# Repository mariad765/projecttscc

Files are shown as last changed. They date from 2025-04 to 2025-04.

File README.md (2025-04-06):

# projecttscc
date: 2025

# Proiect: OpenBook
Acest proiect utilizează Autodesk Fusion 360 pentru realizarea designului carcasei și a plăcii PCB pentru OpenBook, având la bază microcontrollerul ESP32-C6. Include senzori, module de alimentare și componente conectate prin diverse interfețe.

# Diagrama Bloc

### General:
```
+------------------------+     +------------------------+     +------------------------+
| USB-C + ESD Protection | --> | LDO Voltage Regulator  | --> | Li-Po Charging Ctrl.   |
+------------------------+     +------------------------+     +------------------------+
                                                            |
                                                            v
                                                      +----------------+
                                                      |   Battery      |
                                                      | (3.7V Li-Po)   |
                                                      +----------------+
                                                            |
                                                            v
+------------------+     +------------------+         +-------------------+
| RTC DS3231SN     |<--->|   ESP32-C6       |<------->| E-Paper Display   |
+------------------+     +------------------+         | (Header + Driver) |
                           ^    ^   ^   ^              +-------------------+
                           |    |   |   |
       +------------------+    |   |   +--------------------+
       |                       |   |                        |
       v                       v   v                        v
+--------------+       +--------------+           +----------------------+
| SD Card Slot |       | BME688 Sensor|           | External Flash 64MB  |
+--------------+       +--------------+           +----------------------+
                           ^   |
                           |   v
               +-----------------------------+
               | Voltage Supervisor + Reset  |
               | Boot / IO Button Module     |
               +-----------------------------+

                           ^
                           |
                    +-------------+
                    | EPD Power   |
                    +-------------+

                           ^
                           |
              +-----------------------+
              | SPI ESD Protection    |
              +-----------------------+

                           ^
                           |
            +--------------------------+
            | Qwic / Stemma QT Header |
            +--------------------------+

                           ^
                           |
                     +-----------+
                     | Test Pads |
                     +-----------+

```

### Organizarea componentelor mici:
```

                        +------------------------+
                        | USB-C + ESD Protection |
                        | R1, F1, D1             |
                        +-----------+------------+
                                    |
                                    v
                      +-----------------------------+
                      | LDO Voltage Regulator       |
                      | U4 (XC6220)                 |
                      | D2 (Schottky)               |
                      | C1, C2 (Capacitors)         |
                      +-----------+-----------------+
                                  |
                                  v
          +----------------------------------------------+
          | Li-Po Charging Controller (MCP73831)         |
          | RPROG, C1_BAT, C2_BAT                        |
          +--------------------+-------------------------+
                               |
                               v
                          +---------+
                          | Battery |
                          +---------+

          +------------------------------------------+
          |                ESP32-C6                  |
          | U2, conectat cu GPIO la toate modulele   |
          +--+--------+----------+----------+--------+
             |        |          |          |
             |        |          |          |
             |        |          |          |
             v        v          v          v
+------------------+ +------------------+ +-------------------+ +-------------------+
| RTC DS3231SN     | | BME688 Sensor    | | E-Paper Display   | | External NOR Flash|
| U3, C1, C2       | | Ux, Cx (Filter)  | | Header + Drive    | | U1, Cx (Decouple) |
| + CRYSTAL        | | R (Pull-ups)     | | Q3 (MOSFET),      | |                   |
+------------------+ +------------------+ | L1 (Inductor),    | +-------------------+
                                          | D3, D4 (Diodes)   |
                                          | C3, C4, C5, C6    |
                                          +-------------------+

                      +------------------------------------+
                      | SD Card Module (SPI)              |
                      | + Pull-up Resistors               |
                      +------------------------------------+
                      +--------------------------------------------+
                      | Voltage Supervisor + Boot + Reset Buttons  |
                      | Ux (BD52), R1, R2, C1, C2                   |
                      +--------------------------------------------+
                      +------------------+ +--------------------+
                      | EPD Power        | | SPI ESD Protection |
                      | Zener Diode      | | TVS Diodes         |
                      +------------------+ +--------------------+
                      +---------------------------+
                      | Qwiic / Stemma QT Header  |
                      | 4-Pin Connector           |
                      +---------------------------+

                      +---------------------------+
                      | Test Pads (TP1 - TP17)    |
                      +---------------------------+

```

#### Legenda componente:
R = Rezistențe (pull-up, pull-down, programare)

C = Condensatori (filtrare, decuplare, bypass)

D = Diode (Schottky, Zener, TVS)

Q = Tranzistori (MOSFET, BJT)

L = Bobine (inductoare pentru EPD)

U = Integrate (ESP32-C6, MCP73831, etc.)

TP = Test Pads

CRYSTAL = Oscilator 32.768kHz pentru RTC

<prev>

| **Device** | **Datasheet** | **Purchase URL** | **Notes** |
|---|---|---|---|
| ADAFRUIT_LEDCHIP-LED0603 | [Datasheet](https://dammedia.osram.info/media/resource/hires/osram-dam-5178061/LH%20R974_EN.pdf) | [Purchase](https://eu.mouser.com/ProductDetail/ams-OSRAM/LH-R974?qs=rUek3o0zKEvmwAoLLbCfCQ%3D%3D) | |
| ESP32_WROVER_EAGLE-LTSPICE_RR0402 | [Datasheet](https://eu.mouser.com/datasheet/2/447/PYu_RT_1_to_0_01_RoHS_L_15-3461507.pdf) | [Purchase](https://eu.mouser.com/ProductDetail/YAGEO/RT0402BRE072KL?qs=gY0y7AQI9SOEMRqvTCljCA%3D%3D) | |
| ESP32_WROVER_EAGLE-LTSPICE_RR0402 | [Datasheet](https://eu.mouser.com/datasheet/2/447/PYu_SR_20105_RoHS_L_12-3461462.pdf) | [Purchase](https://eu.mouser.com/ProductDetail/YAGEO/SR0402FR-0710KL?qs=TyBUSTk9pD%2F02BJ2PplVgA%3D%3D) | |
| EAGLE-LTSPICE_CC0402 | [Datasheet](https://eu.mouser.com/datasheet/2/447/KEM_C1003_C0G_SMD-3316496.pdf) | [Purchase](https://eu.mouser.com/ProductDetail/KEMET/C0402C100J4GACTU?qs=mjekseImwbbdX0mMb15eGA%3D%3D) | |
| SJ | [Datasheet](https://www.snapeda.com/parts/5112/Keystone%20Electronics/datasheet/) | [Purchase](https://eu.mouser.com/ProductDetail/Keystone-Electronics/5112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) | |
| ESP32_WROVER_EAGLE-LTSPICE_RR0402 | [Datasheet](https://eu.mouser.com/datasheet/2/447/PYu_RC_Group_51_RoHS_L_12-3368608.pdf) | [Purchase](https://eu.mouser.com/ProductDetail/YAGEO/RC0402FR-07226RL?qs=ZELcmBmapfyYDZKSOq20kw%3D%3D) | |
| EAGLE-LTSPICE_CC0402 | [Datasheet](https://eu.mouser.com/datasheet/2/447/KEM_C1018_X7R_SnPb_SMD-3316276.pdf) | [Purchase](https://eu.mouser.com/ProductDetail/KEMET/C0402C104K4RAL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) | |
| ESP32_WROVER_EAGLE-LTSPICE_CC0402 | [Datasheet](https://eu.mouser.com/datasheet/2/447/KEM_C1002_X7R_SMD-3316098.pdf) | [Purchase](https://eu.mouser.com/ProductDetail/KEMET/C0402C104K4RAC?qs=sykUljcfnH1GXndxGT8AHQ%3D%3D) | |
| RCL_CPOL-EUCT3528 | [Datasheet](https://www.snapeda.com/parts/OF-SMD3528WC/Optoflash/datasheet/) | [Purchase](https://www.tme.eu/en/details/of-smd3528wc/smd-white-leds/optoflash/) | |
| ESP32_WROVER_EAGLE-LTSPICE_CC0402 | [Datasheet](https://eu.mouser.com/datasheet/2/447/KEM_C1018_X7R_SnPb_SMD-3316276.pdf) | [Purchase](https://eu.mouser.com/ProductDetail/KEMET/C0402C104K4RAL?qs=pIZUS6sqCWCaMuP2QVR%2Fog%3D%3D) | |
| 112A-TAAR-R03_ATTEND | [Datasheet](https://www.snapeda.com/parts/112A-TAAR-R03/Attend/datasheet/) | [Purchase](https://www.tme.eu/ro/details/mcc-sdmicro/conectori-pentru-cartele/attend/112a-taar-r03/) | |
| EAGLE-LTSPICE_CC0402 | [Datasheet](https://eu.mouser.com/datasheet/2/447/KEM_C1006_X5R_SMD-3316465.pdf) | [Purchase](https://eu.mouser.com/ProductDetail/KEMET/C0402C475M9PAC7411?qs=cpo3%2FpBou2jRzZxyxJnMGg%3D%3D) | |
| ESP32_WROVER_SPARKFUN-DISCRETESEMI_MOSFET_PCH-DMG2305UX-7 | [Datasheet](https://www.diodes.com/assets/Datasheets/DMG2305UX.pdf) | [Purchase](https://eu.mouser.com/ProductDetail/Diodes-Incorporated/DMG2305UX-7?qs=L1DZKBg7t5F%2FNBHrjfxC%252Bg%3D%3D) | |
| 744043680IND_4828-WE-TPC_WRE | [Datasheet](https://www.we-online.com/components/products/datasheet/744043680.pdf) | [Purchase](https://eu.mouser.com/ProductDetail/Wurth-Elektronik/744043680?qs=PGXP4M47uW6VkZq%252BkzjrHA%3D%3D) | |
| BD5229G-TR | [Datasheet](https://fscdn.rohm.com/en/products/databook/datasheet/ic/power/voltage_detector/bd52xxg-e.pdf) | [Purchase](https://eu.mouser.com/ProductDetail/ROHM-Semiconductor/BD5229G-TR?qs=4kLU8WoGk0vvnhrrYwdszw%3D%3D) | |
| ESP32_WROVER_BME680_BME680 | [Datasheet](https://eu.mouser.com/datasheet/2/783/bst_bme688_fl000-2307034.pdf) | [Purchase](https://eu.mouser.com/ProductDetail/Bosch-Sensortec/BME688?qs=IS%252B4QmGtzzqQoVDscqwx3A%3D%3D) | |
| BUTTON_CUSYOMV1 | [Datasheet](https://www.ckswitches.com/media/1482/kms.pdf) | [Purchase](https://eu.mouser.com/ProductDetail/CK/KMS231G?qs=cygERTaPE9Aulmq4rq4WXQ%3D%3D) | [see note 1] |
| CPH3225A | [Datasheet](https://eu.mouser.com/datasheet/2/360/Seiko_Instruments_MicroBattery_E_20230330_2024Jan_-3561061.pdf) | [Purchase](https://eu.mouser.com/ProductDetail/Seiko-Semiconductors/CPH3225A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) | |
| DS3231SN# | [Datasheet](https://eu.mouser.com/datasheet/2/609/DS3231-3421123.pdf) | [Purchase](https://www.snapeda.com/api/url_track_click_mouser/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) | |
| ESP32-C6-WROOM-1-N8 | [Datasheet](https://eu.mouser.com/datasheet/2/891/Espressif_ESP32_C6_WROOM_1__Datasheet_V0_1_PRELIMI-3239987.pdf) | [Purchase](https://eu.mouser.com/ProductDetail/Espressif-Systems/ESP32-C6-WROOM-1-N8?qs=8Wlm6%252BaMh8ST02Gmwp74cw%3D%3D) | |
| ESP32C6_VARISTORCN1812 | [Datasheet](https://www.snapeda.com/parts/PFMF.050.2/Schurter/datasheet/) | [Purchase](https://www.digikey.com/en/products/detail/schurter-inc/PFMF-050-2/1731348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) | |
| ESP32_WROVER_AVX---SD0805S020S1R0_AVX_SD0805S020S1R0_0_0AVX_SD0805S020S1R0_0_0 | [Datasheet](http://datasheets.avx.com/schottky.pdf) | [Purchase](https://www.kyocera-avx.com/products/diodes/lead-less-chip-schottky-barrier-diodes/) | |
| ESP32_WROVER_SPARKFUN-IC-POWER_MCP73831 | [Datasheet](https://eu.mouser.com/datasheet/2/268/MCP73831_Family_Data_Sheet_DS20001984H-3441711.pdf) | [Purchase](https://eu.mouser.com/ProductDetail/Microchip-Technology/MCP73831T-2ACI-OT?qs=yUQqVecv4qvbBQBGbHx0Mw%3D%3D) | |
| FH34SRJ-24S-0.5SH_99_ | [Datasheet](https://www.snapeda.com/parts/FH34SRJ-24S-0.5SH(99)/Hirose%20Electric/datasheet/) | [Purchase](https://www.digikey.com/en/products/detail/hirose-electric-co-ltd/FH34SRJ-24S-0-5SH-99/5132529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) | |
| MAX17048G+T10 | [Datasheet](https://eu.mouser.com/datasheet/2/609/MAX17048_MAX17049-3469099.pdf) | [Purchase](https://www.snapeda.com/api/url_track_click_mouser/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) | |
| MBR0530 | [Datasheet](https://www.onsemi.com/products/discrete-power-modules/schottky-diodes-schottky-rectifiers/mbr0530t3g) | [Purchase](https://www.snapeda.com/api/url_track_click_mouser/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) | |
| PGB1010603MR | [Datasheet](https://www.littelfuse.com/assetdocs/pulseguard-esd-suppressors-pgb1-datasheet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) | [Purchase](https://www.snapeda.com/api/url_track_click_mouser/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) | 
| QWIIC_CONNECTORJS-1MM | [Qwiic Connector Datasheet](https://eu.mouser.com/datasheet/2/813/Qwiic_Connector_Datasheet-1223982.pdf) | [SparkFun Product](https://eu.mouser.com/ProductDetail/SparkFun/PRT-14417?qs=wd5RIQLrsJhgdz%2FpmZ%2F3GQ%3D%3D) | |
| SAMACSYS_PARTS_USB4110-GF-A | [USB4110 Product Drawing](https://eu.mouser.com/datasheet/2/837/GCT_USB4110_Product_Drawing___20k_cycles-3455479.pdf) | [GCT Product](https://eu.mouser.com/ProductDetail/GCT/USB4110-GF-A?qs=KUoIvG%2F9IlYiZvIXQjyJeA%3D%3D) | |
| SI1308EDL-T1-GE3 | [SI1308EDL Datasheet](https://www.vishay.com/docs/63399/si1308edl.pdf) | [Vishay Product](https://eu.mouser.com/ProductDetail/Vishay-Semiconductors/SI1308EDL-T1-GE3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) | |
| TPTP20R | [TPTP20R Datasheet](https://eu.mouser.com/datasheet/2/215/000-5004-741320.pdf)  | [Keystone Product](https://eu.mouser.com/ProductDetail/Keystone-Electronics/5000?qs=q0tsjPZWdm%252B9SiiTAbEwUw%3D%3D) | [see note 2] |
| USBLC6-2SC6Y | [USBLC6-2SC6Y Datasheet](https://eu.mouser.com/datasheet/2/389/usblc6_2sc6y-1852505.pdf) | [STMicroelectronics Product](https://eu.mouser.com/ProductDetail/STMicroelectronics/USBLC6-2SC6Y?qs=gNDSiZmRJS%2FOgDexvXkdow%3D%3D) | |
| W25Q512JVEIQ | [W25Q512JVEIQ Datasheet](https://eu.mouser.com/datasheet/2/949/Winbond_W25Q512JV_Datasheet-3240039.pdf) | [Winbond Product](https://eu.mouser.com/ProductDetail/Winbond/W25Q512JVEIQ?qs=l7cgNqFNU1jw6svr3at6tA%3D%3D) | |
| XC6220A331MR-G | [XC6220A331MR-G Datasheet](https://eu.mouser.com/datasheet/2/760/xc6220-3371556.pdf) | [Torex Semiconductor Product](https://eu.mouser.com/ProductDetail/Torex-Semiconductor/XC6220A331MR-G?qs=AsjdqWjXhJ8ZSWznL1J0gg%3D%3D) | |

</prev>

[note 1] - 
<prev>
✅ Side-Actuated Tactile Switches (Compatible with KMR2 footprint)
1. C&K KMS231G LFS
🔹 Size: 4.6 mm × 2.8 mm
🔹 Height: 1.9 mm
🔹 Actuation Force: 2.6 N
🔹 Type: Side push (side-actuated)
🔹 Mounting: SMT
🔹 Footprint Compatibility: ✅ (Matches KMR2 pad spacing)
</prev>
[note 2] - 
<prev>
TP20R is often associated with a round, 2.0 mm diameter test pad.
Here’s a commonly used and widely available match:

✅ Keystone Electronics 5000 Series
Model: Keystone 5000
Type: SMT Test Point
Material: Phosphor bronze
Plating: Tin over Nickel
Pad Diameter: Fits 2.0 mm pad
Mounting: Surface Mount
Aplication: General purpose test point for probes

✅ Harwin S1751-46R
Type: SMT Test Point
For Pad: ~2.0 mm diameter
Profile: Low
Finish: Tin
Common in: Test pads designed for probe contact

✅ Alternative: Mill-Max 2501-2-00-80-00-00-07-0
Type: Test Point/Contact Pad
Style: Coined terminal
Footprint Compatibility: Suitable with TP20R
Mount: SMT
Useful for: Precise contact with spring-loaded probes

</prev>

#  Funcționalitate hardware detaliată

Proiectul se bazează pe microcontrollerul ESP32-C6 ce coordonează următoarele module:

Alimentare:
USB-C -> protecție ESD + siguranță resetabilă + diodă Schottky
Regulator LDO 3.3V (XC6220)
MCP73831 încarcă un acumulator Li-Po

Afișaj E-Paper 2.9":
Alimentare dedicată EPD Power + MOSFET pentru control curent
Header 24 pini conectat prin SPI

Modul de ceas RTC DS3231SN:
Comunicare I²C
Precizie ridicată, cristale integrate

Senzor BME688:
Comunicare I²C
Măsoară presiune, temperatură, umiditate și compuși volatili

Memorie externă NOR Flash 64MB:
Interfață SPI

Slot SD Card:
SPI + pini selectabili pentru CS

Supraveghetor tensiune + Reset & Boot IO:
Butoane fizice pentru dezvoltare/debug

Protecție ESD (TVS):
Pe toate liniile SPI și I²C critice

Header Qwiic / Stemma QT:
Expansiune rapidă prin I²C

Paduri de test TP1-TP17:
Verificare și depanare ușoară

# Pini ESP32-C6 folosiți

```
| Pin   | Funcție      | Modul conectat                    |
|-------|--------------|-----------------------------------|
| IO2   | SPI CLK      | E-Paper, Flash, SD Card           |
| IO3   | SPI MISO     | Flash, SD Card                    |
| IO4   | SPI MOSI     | E-Paper, Flash, SD Card           |
| IO5   | SPI CS (selectabil) | Flash                          |
| IO6   | SPI CS       | SD Card                           |
| IO7   | SPI CS       | E-Paper                           |
| IO8   | I²C SDA      | RTC, BME688, Qwiic                |
| IO9   | I²C SCL      | RTC, BME688, Qwiic                |
| EN    | Enable       | Buton de reset                    |
| IO0   | Boot         | Buton boot                        |

```

# Alte resurse relevante

-> Design log: toate PCB-urile au fost create în Fusion 360 Electronics, folosind standarde de rutare pentru 3.3V și SPI/I²C.

-> Testare și depanare: TP1-TP17 permit sondare pentru verificare semnal

# Licență

Distribuit sub licența GNU GPL v3. Pentru detalii, consultă fișierul LICENSE din acest repository.

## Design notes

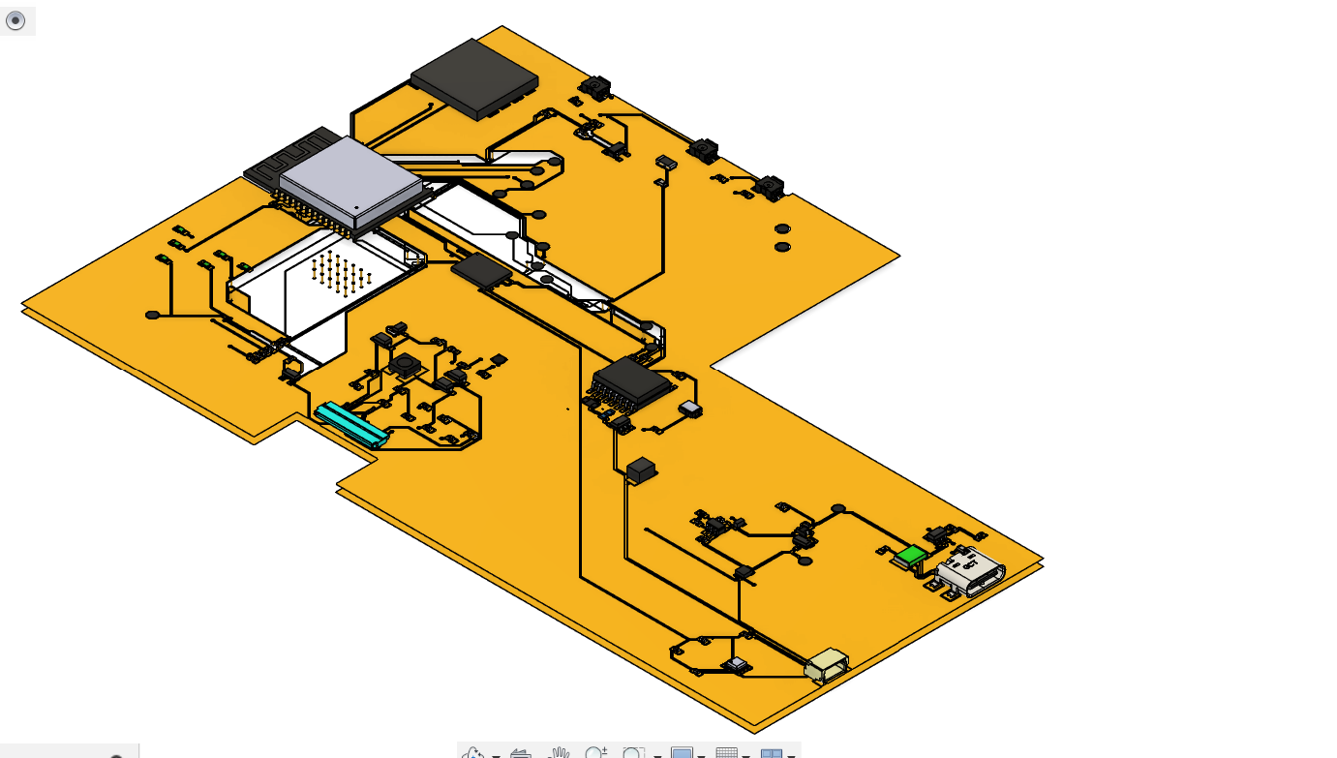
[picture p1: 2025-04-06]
Images/3d_placa.png

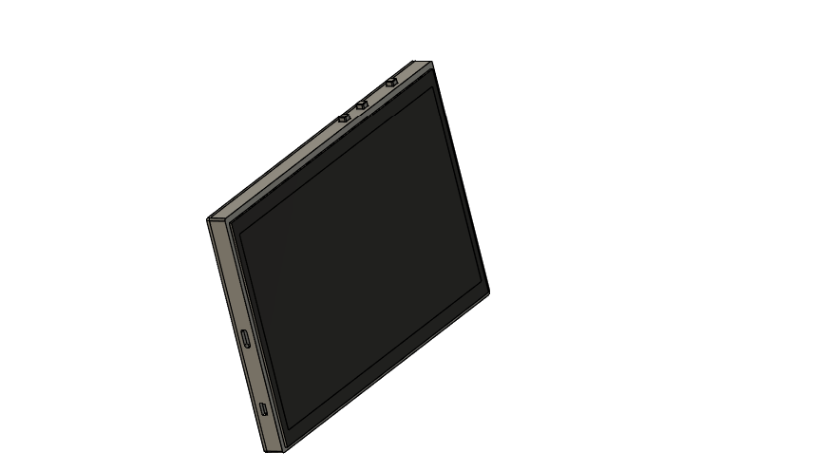
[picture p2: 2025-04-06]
Images/3d_dispozitiv.png

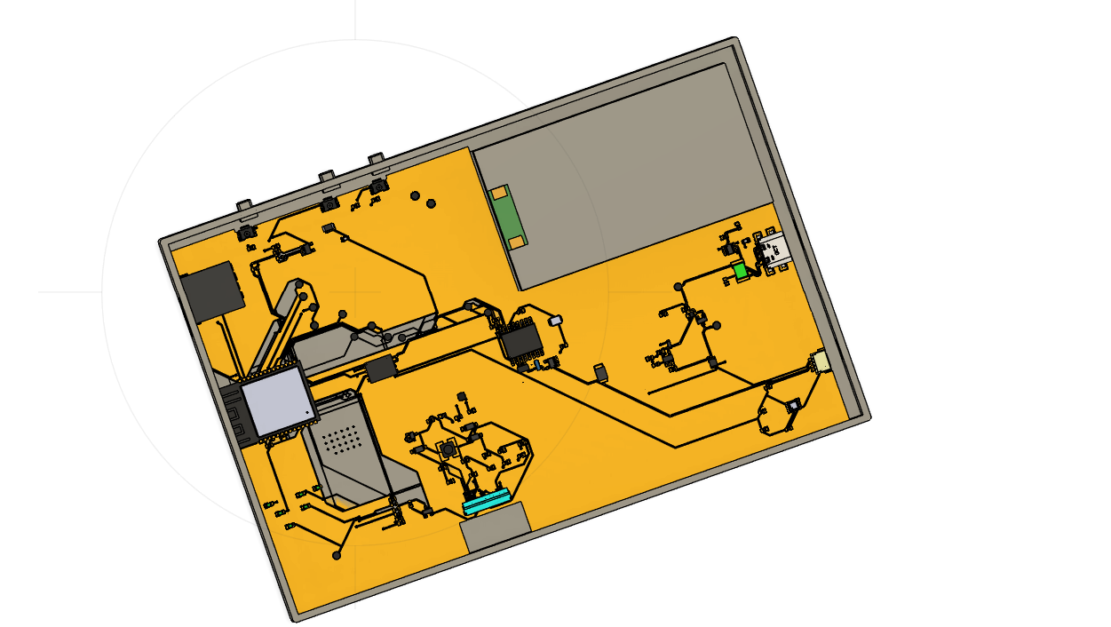
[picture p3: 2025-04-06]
Images/3d_dispozitiv_no lid.png

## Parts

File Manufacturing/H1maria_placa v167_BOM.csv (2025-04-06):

Device | DATASHEET | PURCHASE-URL
ADAFRUIT_LEDCHIP-LED0603 | https://dammedia.osram.info/media/resource/hires/osram-dam-5178061/LH%20R974_EN.pdf | https://eu.mouser.com/ProductDetail/ams-OSRAM/LH-R974?qs=rUek3o0zKEvmwAoLLbCfCQ%3D%3D
ESP32_WROVER_EAGLE-LTSPICE_RR0402
SJ
EAGLE-LTSPICE_CC0402
ESP32_WROVER_EAGLE-LTSPICE_RR0402
ESP32_WROVER_EAGLE-LTSPICE_RR0402
EAGLE-LTSPICE_CC0402
ESP32_WROVER_EAGLE-LTSPICE_CC0402
RCL_CPOL-EUCT3528
ESP32_WROVER_EAGLE-LTSPICE_RR0402
ESP32_WROVER_EAGLE-LTSPICE_CC0402
112A-TAAR-R03_ATTEND
ESP32_WROVER_EAGLE-LTSPICE_RR0402
EAGLE-LTSPICE_CC0402
EAGLE-LTSPICE_CC0402
ESP32_WROVER_EAGLE-LTSPICE_RR0402
ESP32_WROVER_EAGLE-LTSPICE_RR0402
ESP32_WROVER_SPARKFUN-DISCRETESEMI_MOSFET_PCH-DMG2305UX-7
ESP32_WROVER_EAGLE-LTSPICE_RR0402
EAGLE-LTSPICE_CC0402
ESP32_WROVER_EAGLE-LTSPICE_CC0402
ESP32_WROVER_EAGLE-LTSPICE_RR0402
744043680IND_4828-WE-TPC_WRE
BD5229G-TR
ESP32_WROVER_BME680_BME680
BUTTON_CUSYOMV1
CPH3225A |  | https://www.snapeda.com/api/url_track_click_mouser/?unipart_id=562593&manufacturer=Seiko Instruments&part_name=CPH3225A&search_term=None
DS3231SN# |  | https://www.snapeda.com/api/url_track_click_mouser/?unipart_id=99048&manufacturer=Analog Devices&part_name=DS3231SN#&search_term=None
ESP32-C6-WROOM-1-N8
ESP32C6_VARISTORCN1812
ESP32_WROVER_AVX---SD0805S020S1R0_AVX_SD0805S020S1R0_0_0AVX_SD0805S020S1R0_0_0 | http://datasheets.avx.com/schottky.pdf
ESP32_WROVER_SPARKFUN-IC-POWER_MCP73831
FH34SRJ-24S-0.5SH_99_
MAX17048G+T10 |  | https://www.snapeda.com/api/url_track_click_mouser/?unipart_id=329239&manufacturer=Analog Devices&part_name=MAX17048G+T10&search_term=None
MBR0530 |  | https://www.snapeda.com/api/url_track_click_mouser/?unipart_id=179458&manufacturer=ON Semiconductor&part_name=MBR0530&search_term=None
PGB1010603MR |  | https://www.snapeda.com/api/url_track_click_mouser/?unipart_id=5659453&manufacturer=Littelfuse Inc.&part_name=PGB1010603MR&search_term=None
QWIIC_CONNECTORJS-1MM
SAMACSYS_PARTS_USB4110-GF-A
ESP32_WROVER_AVX---SD0805S020S1R0_AVX_SD0805S020S1R0_0_0AVX_SD0805S020S1R0_0_0 | http://datasheets.avx.com/schottky.pdf
SI1308EDL-T1-GE3
TPTP20R
USBLC6-2SC6Y
W25Q512JVEIQ
XC6220A331MR-G

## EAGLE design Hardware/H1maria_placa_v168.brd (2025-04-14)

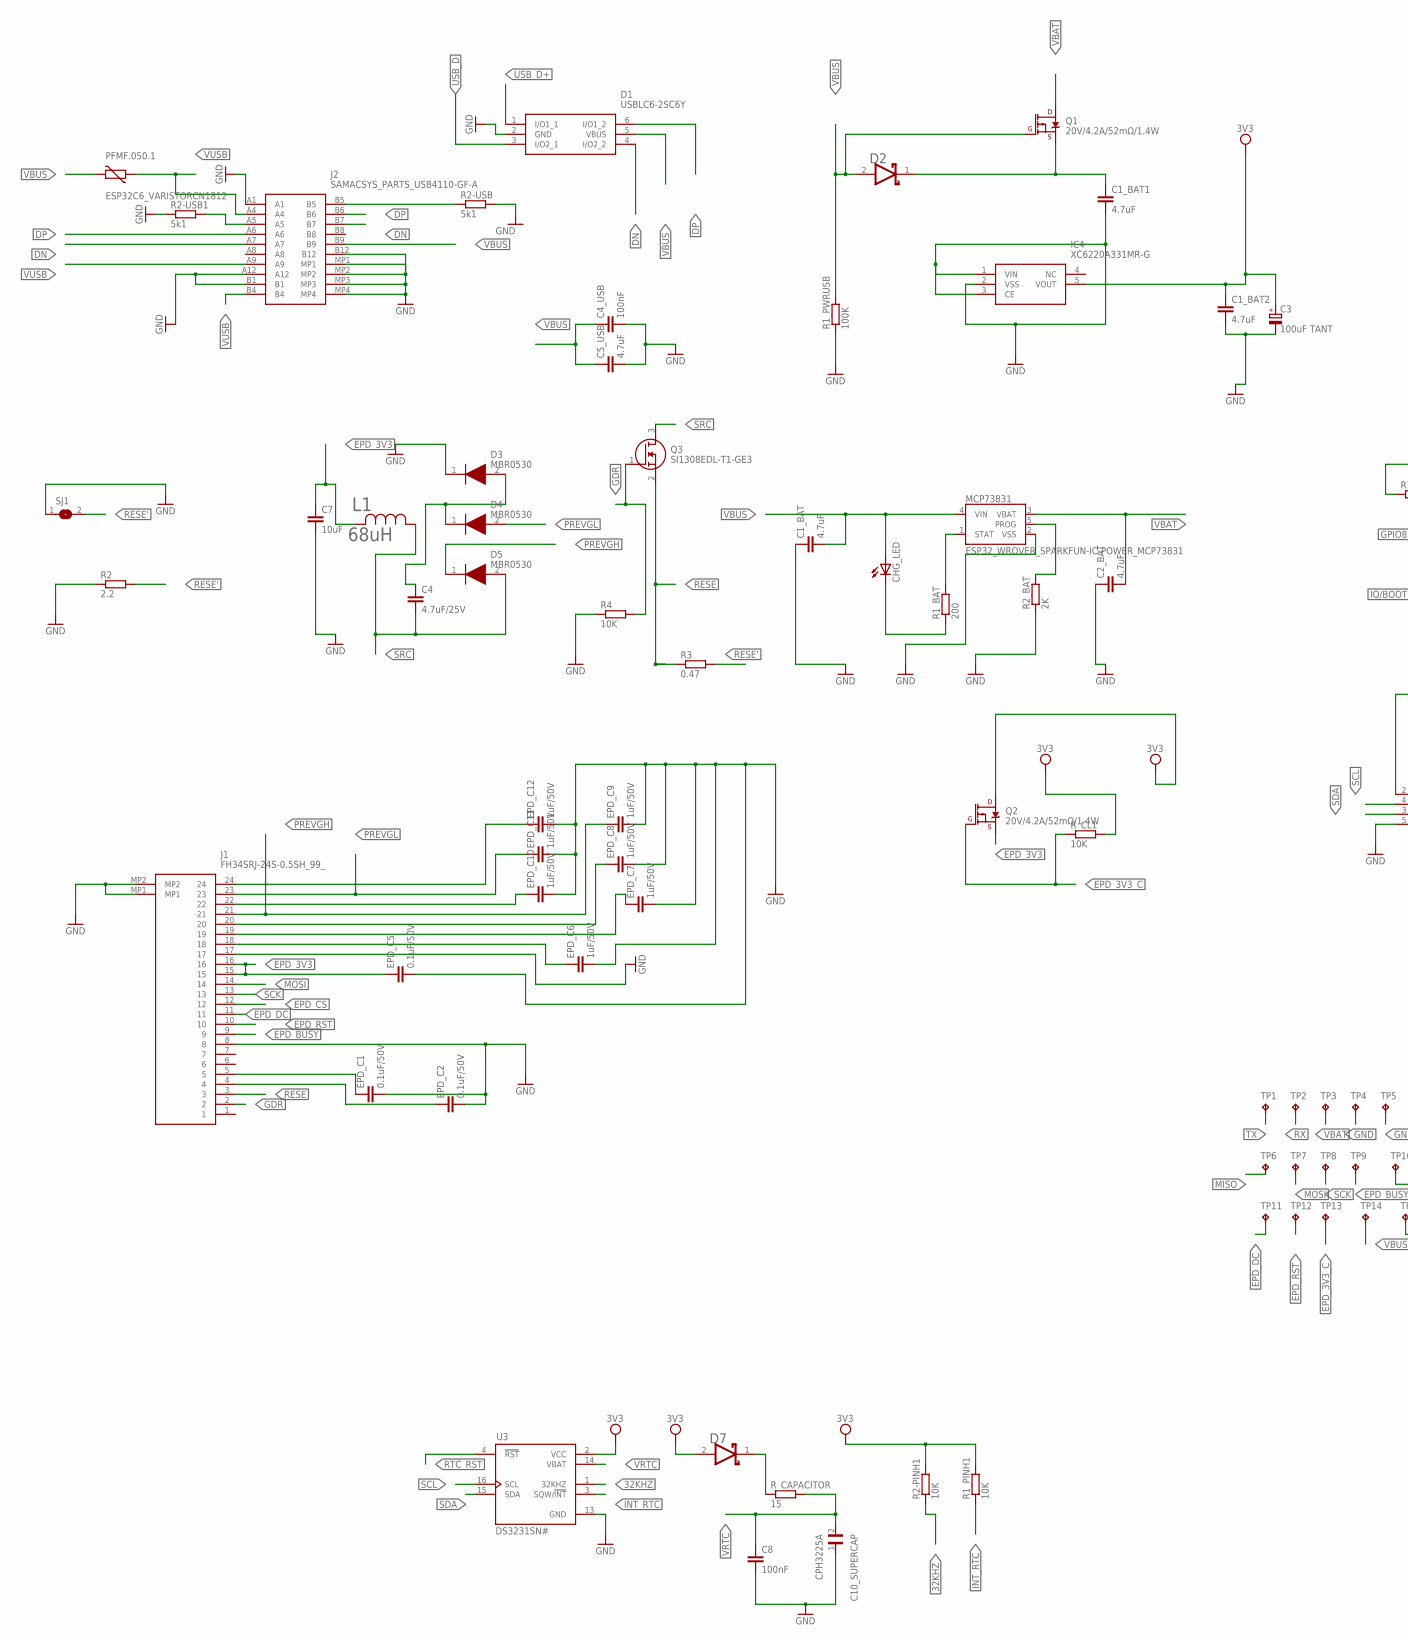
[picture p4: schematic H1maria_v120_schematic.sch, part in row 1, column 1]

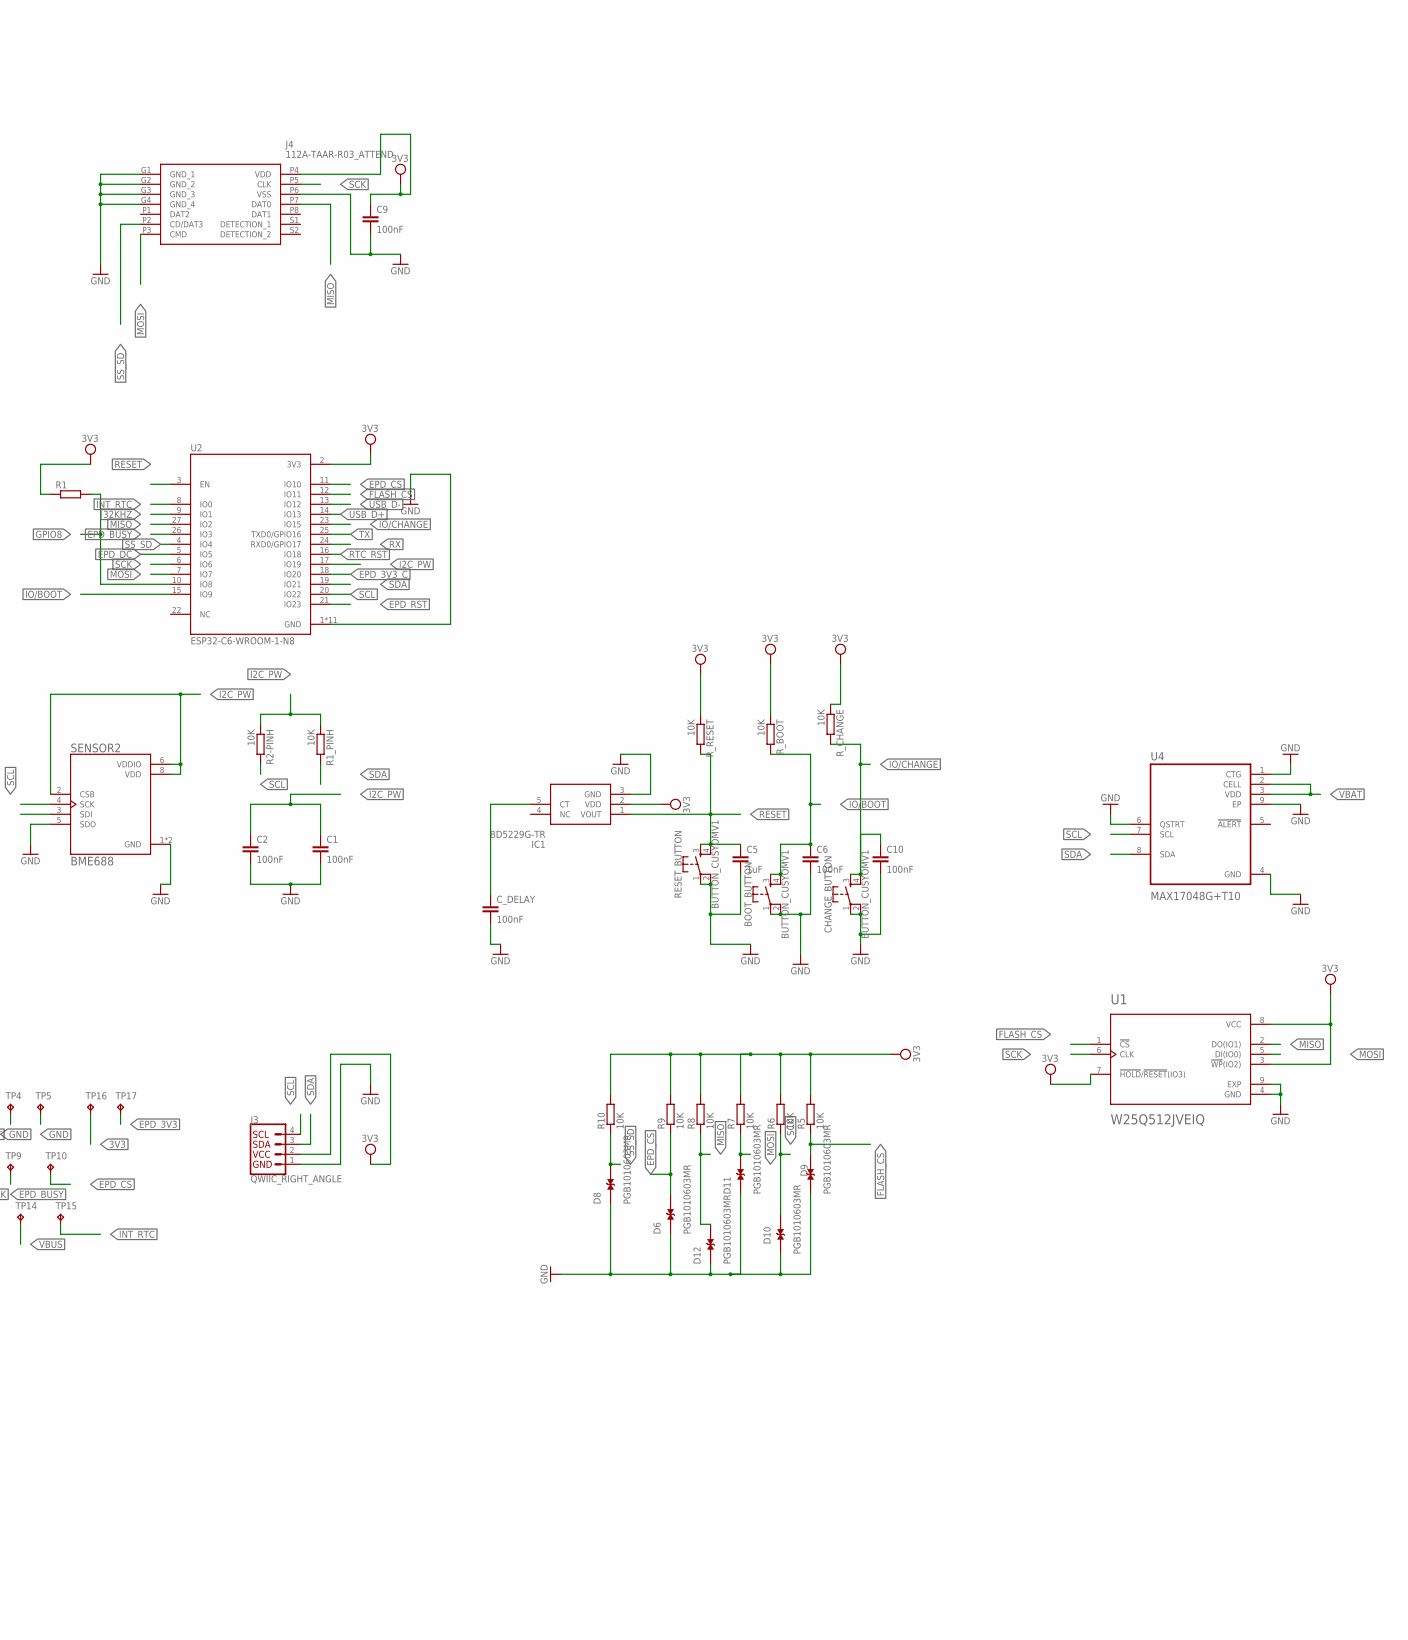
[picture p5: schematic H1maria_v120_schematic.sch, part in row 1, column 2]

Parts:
BOOT_BUTTON: BUTTON_CUSYOMV1; MYBUTTON
C1, C2, C9: 100nF; ESP32_WROVER_EAGLE-LTSPICE_C0402
C1_BAT, C1_BAT1, C1_BAT2, C2_BAT, C5_USB: 4.7uF; EAGLE-LTSPICE_C0402
C3: 100uF TANT; RCL_CT3528
C4: 4.7uF/25V; ESP32_WROVER_EAGLE-LTSPICE_C0402
C4_USB, C6, C8, C10: 100nF; EAGLE-LTSPICE_C0402
C5: 1uF; EAGLE-LTSPICE_C0402
C7: 10uF; ESP32_WROVER_EAGLE-LTSPICE_C0402
C10_SUPERCAP: CPH3225A; CAPCP3225X100N
CHANGE_BUTTON: BUTTON_CUSYOMV1; MYBUTTON
CHG_LED: ADAFRUIT_LEDCHIP-LED0603; ADAFRUIT_CHIP-LED0603
C_DELAY: 100nF; EAGLE-LTSPICE_C0402
D1: USBLC6-2SC6Y; SOT95P280X145-6N
D2: SD0805S020S1R0; ESP32_WROVER_AVX---SD0805S020S1R0_AVX_SD0805S020S1R0_0
D3, D4, D5: MBR0530; SOD3716X135N
D6, D8, D9, D10, D11, D12: PGB1010603MR; DIOC1608X36N
D7: ESP32_WROVER_AVX---SD0805S020S1R0_AVX_SD0805S020S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; ESP32_WROVER_AVX---SD0805S020S1R0_AVX_SD0805S020S1R0_0
EPD_C1, EPD_C2, EPD_C5: 0.1uF/50V; EAGLE-LTSPICE_C0402
EPD_C6, EPD_C7, EPD_C8, EPD_C9, EPD_C10, EPD_C11, EPD_C12: 1uF/50V; EAGLE-LTSPICE_C0402
IC1: BD5229G-TR; SOT95P280X125-5N
IC4: XC6220A331MR-G; SOT95P280X120-5N
J1: FH34SRJ-24S-0.5SH_99_; FH34SRJ24S05SH99
J2: SAMACSYS_PARTS_USB4110-GF-A; SAMACSYS_PARTS_USB4110GFA
J3: QWIIC_RIGHT_ANGLE; JST04_1MM_RA
J4: 112A-TAAR-R03_ATTEND; 112ATAARR03ATTEND
L1: 68uH; IND_4828-WE-TPC_WRE
MCP73831: ESP32_WROVER_SPARKFUN-IC-POWER_MCP73831; ESP32_WROVER_SPARKFUN-IC-POWER_SOT23-5
PFMF.050.1: ESP32C6_VARISTORCN1812; ESP32C6_VARISTOR_CT/CN1812
Q1, Q2: 20V/4.2A/52mΩ/1.4W; ESP32_WROVER_SPARKFUN-DISCRETESEMI_SOT23-3
Q3: SI1308EDL-T1-GE3; SOT65P210X110-3N
R1: ESP32_WROVER_EAGLE-LTSPICE_RR0402; ESP32_WROVER_EAGLE-LTSPICE_R0402
R1_BAT: 200; ESP32_WROVER_EAGLE-LTSPICE_R0402
R1_PINH, R1_PINH1, R2-PINH, R2-PINH1, R4, R5, R6, R7, R8, R9, R10: 10K; ESP32_WROVER_EAGLE-LTSPICE_R0402
R1_PWRUSB: 100K; ESP32_WROVER_EAGLE-LTSPICE_R0402
R2: 2.2; ESP32_WROVER_EAGLE-LTSPICE_R0402
R2-USB, R2-USB1: 5k1; ESP32_WROVER_EAGLE-LTSPICE_R0402
R2_BAT: 2K; ESP32_WROVER_EAGLE-LTSPICE_R0402
R3: 0.47; ESP32_WROVER_EAGLE-LTSPICE_R0402
RESET_BUTTON: BUTTON_CUSYOMV1; MYBUTTON
R_BOOT: 10K; ESP32_WROVER_EAGLE-LTSPICE_R0402
R_CAPACITOR: 15; ESP32_WROVER_EAGLE-LTSPICE_R0402
R_CHANGE: 10K; ESP32_WROVER_EAGLE-LTSPICE_R0402
R_CL1: 10K; ESP32_WROVER_EAGLE-LTSPICE_R0402
R_RESET: 10K; ESP32_WROVER_EAGLE-LTSPICE_R0402
SENSOR2: BME688; ESP32_WROVER_BME680_PSON80P300X300X100-8N
SJ1: SJ
TP1, TP2, TP3, TP4, TP5, TP6, TP7, TP8, TP9, TP10, TP11, TP12, TP13, TP14, TP15, TP16, TP17: TPTP20R; TP20R
U1: W25Q512JVEIQ; SON127P600X800X80-9N
U2: ESP32-C6-WROOM-1-N8; XCVR_ESP32-C6-WROOM-1-N8
U3: DS3231SN#; SOIC127P1032X265-16N
U4: MAX17048G+T10; SON50P200X200X80-9N

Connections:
3V3: C1_BAT2.1, C3.+, C9.1, D7.2 (ANODE), IC1.2 (VDD), IC4.5 (VOUT), J3.2, J4.P4 (VDD), Q2.3 (D), R1.1, R1_PINH1.2, R2-PINH1.2, R5.2, R6.2, R7.2, R8.2, R9.2, R10.2, R_BOOT.1, R_CHANGE.1, R_CL1.2, R_RESET.1, TP16.TP, U1.3 (!WP!(IO2)), U1.7 (!HOLD!/!RESET!(IO3)), U1.8 (VCC), U2.2 (3V3), U3.2 (VCC)
32KHZ: R2-PINH1.1, U2.9 (IO1), U3.1 (32KHZ)
DN: D1.4 (I/O2_2), J2.A7, J2.B7
DP: D1.6 (I/O1_2), J2.A6, J2.B6
EPD_3V3: C7.1, EPD_C5.1, J1.15, J1.16, L1.2, Q2.2 (S), TP17.TP
EPD_3V3_C: Q2.1 (G), R_CL1.1, TP13.TP, U2.18 (IO20)
EPD_BUSY: J1.9, TP9.TP, U2.26 (IO3)
EPD_CS: D6.2, J1.12, R9.1, TP10.TP, U2.11 (IO10)
EPD_DC: J1.11, TP11.TP, U2.5 (IO5)
EPD_RST: J1.10, TP12.TP, U2.21 (IO23)
FLASH_CS: D9.2, R5.1, U1.1 (!CS), U2.12 (IO11)
GDR: J1.2, Q3.1 (G), R4.2
GND: BOOT_BUTTON.1, BOOT_BUTTON.2, C1.2, C1_BAT.1, C1_BAT1.2, C1_BAT2.2, C2.2, C2_BAT.1, C3.-, C4_USB.2, C5.2, C5_USB.2, C6.2, C7.2, C8.2, C9.2, C10.2, C10_SUPERCAP.1, CHANGE_BUTTON.1, CHANGE_BUTTON.2, C_DELAY.2, D1.2 (GND), D3.1 (K), D6.1, D8.1, D9.1, D10.1, D11.1, D12.1, EPD_C1.2, EPD_C2.2, EPD_C5.2, EPD_C6.2, EPD_C7.2, EPD_C8.2, EPD_C9.2, EPD_C10.2, EPD_C11.2, EPD_C12.2, IC1.3 (GND), IC4.1 (VIN), IC4.2 (VSS), IC4.3 (CE), J1.8, J1.17, J1.MP1, J1.MP2, J2.A1, J2.A12, J2.B1, J2.B12, J2.MP1, J2.MP2, J2.MP3, J2.MP4, J3.1, J4.G1 (GND_1), J4.G2 (GND_2), J4.G3 (GND_3), J4.G4 (GND_4), J4.P6 (VSS), MCP73831.2 (VSS), R1_PWRUSB.1, R2.1, R2-USB.2, R2-USB1.1, R2_BAT.1, R4.1, RESET_BUTTON.1, RESET_BUTTON.2, SENSOR2.1 (GND), SENSOR2.5 (SDO), SENSOR2.7 (GND), SJ1.1, TP4.TP, TP5.TP, U1.4 (GND), U1.9 (EXP), U2.1 (GND), U2.28 (GND), U2.29_1 (GND), U2.29_2 (GND), U2.29_3 (GND), U2.29_4 (GND), U2.29_5 (GND), U2.29_6 (GND), U2.29_7 (GND), U2.29_8 (GND), U2.29_9 (GND), U3.13 (GND), U4.1 (CTG), U4.4 (GND), U4.6 (QSTRT), U4.9 (EP)
GPIO8: R1.2, U2.10 (IO8)
I2C_PW: C1.1, C2.1, R1_PINH.1, R2-PINH.1, SENSOR2.2 (CSB), SENSOR2.6 (VDDIO), SENSOR2.8 (VDD), U2.17 (IO19)
INT_RTC: R1_PINH1.1, TP15.TP, U2.8 (IO0), U3.3 (SQW/!INT)
IO/BOOT: BOOT_BUTTON.3, BOOT_BUTTON.4, C6.1, R_BOOT.2, U2.15 (IO9)
IO/CHANGE: C10.1, CHANGE_BUTTON.3, CHANGE_BUTTON.4, R_CHANGE.2, U2.23 (IO15)
MISO: D12.2, J4.P7 (DAT0), R8.1, TP6.TP, U1.2 (DO(IO1)), U2.27 (IO2)
MOSI: D11.2, J1.14, J4.P3 (CMD), R7.1, TP7.TP, U1.5 (DI(IO0)), U2.7 (IO7)
unnamed: J2.A5, R2-USB1.2
unnamed: J2.B5, R2-USB.1
unnamed: C1_BAT1.1, D2.1 (CATHODE), Q1.2 (S)
unnamed: C4.1, D3.2 (A), D4.1 (K)
unnamed: CHG_LED.C, R1_BAT.1
unnamed: MCP73831.1 (STAT), R1_BAT.2
unnamed: MCP73831.5 (PROG), R2_BAT.2
unnamed: EPD_C12.1, J1.24
unnamed: EPD_C1.1, J1.5
unnamed: EPD_C10.1, J1.22
unnamed: EPD_C2.1, J1.4
unnamed: EPD_C8.1, J1.20
unnamed: EPD_C7.1, J1.19
unnamed: EPD_C6.1, J1.18
unnamed: C_DELAY.1, IC1.5 (CT)
unnamed: D7.1 (CATHODE), R_CAPACITOR.1
PREVGH: D5.1 (K), EPD_C9.1, J1.21
PREVGL: D4.2 (A), EPD_C11.1, J1.23
RESE: J1.3, Q3.2 (S), R3.1
RESE': R2.2, R3.2, SJ1.2
RESET: C5.1, IC1.1 (VOUT), RESET_BUTTON.3, RESET_BUTTON.4, R_RESET.2, U2.3 (EN)
RTC_RST: U2.16 (IO18), U3.4 (!RST)
RX: TP2.TP, U2.24 (RXD0/GPIO17)
SCK: D10.2, J1.13, J4.P5 (CLK), R6.1, TP8.TP, U1.6 (CLK), U2.6 (IO6)
SCL: J3.4, R2-PINH.2, SENSOR2.4 (SCK), U2.20 (IO22), U3.16 (SCL), U4.7 (SCL)
SDA: J3.3, R1_PINH.2, SENSOR2.3 (SDI), U2.19 (IO21), U3.15 (SDA), U4.8 (SDA)
SRC: C4.2, D5.2 (A), L1.1, Q3.3 (D)
SS_SD: D8.2, J4.P2 (CD/DAT3), R10.1, U2.4 (IO4)
TX: TP1.TP, U2.25 (TXD0/GPIO16)
USB_D: D1.3 (I/O2_1)
USB_D+: D1.1 (I/O1_1), U2.14 (IO13)
USB_D-: U2.13 (IO12)
VBAT: C2_BAT.2, MCP73831.3 (VBAT), Q1.3 (D), TP3.TP, U4.2 (CELL), U4.3 (VDD)
VBUS: C1_BAT.2, C4_USB.1, C5_USB.1, CHG_LED.A, D1.5 (VBUS), D2.2 (ANODE), J2.B9, MCP73831.4 (VIN), PFMF.050.1.2, Q1.1 (G), R1_PWRUSB.2, TP14.TP
VRTC: C8.1, C10_SUPERCAP.2, R_CAPACITOR.2, U3.14 (VBAT)
VUSB: J2.A4, J2.A9, J2.B4, PFMF.050.1.1

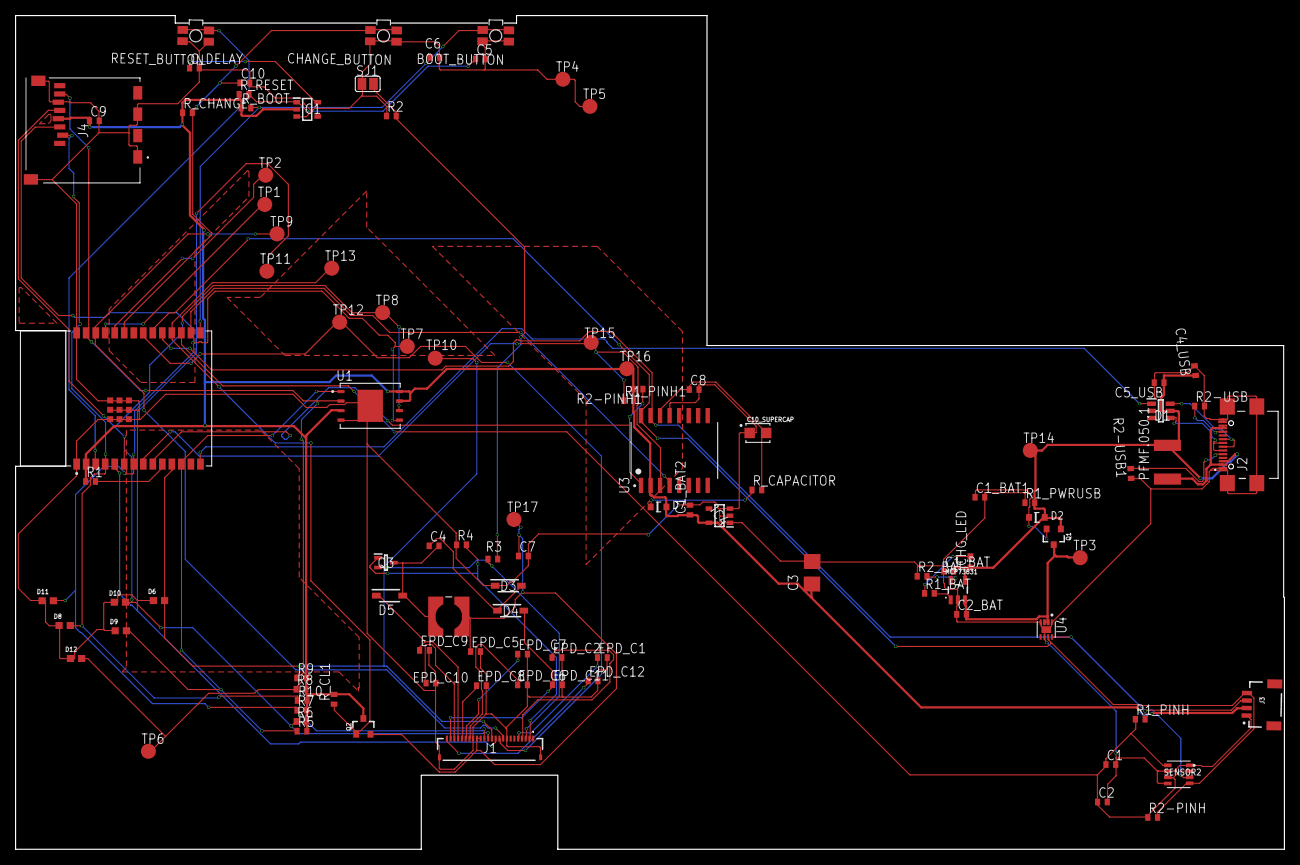
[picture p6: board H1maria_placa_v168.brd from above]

Board: 2 copper layers, 169.2 x 111.2 mm, 103 parts (0 on the bottom side), 54 nets.

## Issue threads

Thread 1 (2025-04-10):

Lipsă frame și organizare schematic

LaviniaTudor003, 2025-04-10:
### **Descriere:**
În versiunea curentă a schematicului proiectului, lipsesc elemente esențiale de organizare vizuală și documentare. Diagrama nu include un frame și nu este structurată pe blocuri funcționale distincte.

### **Problemă:**
În versiunea actuală a schematicului lipsesc:
- Frame-ul
- Împărțirea pe blocuri funcționale
- Aranjarea clară și lizibilă a componentelor și conexiunilor

### **Capturi Relevante:**

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

### **Sugestie:**
- Recomand includerea unui frame standardizat în schematic.
- Reorganizarea schematicului prin gruparea logică a circuitelor în blocuri funcționale.

mariad765, 2025-04-13:
Mulțumesc pentru observații!
Menționez că schematicul a fost validat folosind o lista tehnică detaliată - gasita la link-ul [https://github.com/azonenberg/pcb-checklist/blob/master/schematic-checklist.md], care acoperă toate aspectele esențiale pentru funcționarea corectă a circuitului (ERC curat, decuplări, protecții, pinout, test points, etc.).

Aspectele menționate în acest issue (frame, organizare pe blocuri funcționale, aranjare vizuală) țin mai mult de partea estetică și nu sunt incluse în checklist-ul de validare tehnică. Ele nu afectează funcționalitatea sau corectitudinea schematicului în stadiul actual.

Closed 2025-04-13.

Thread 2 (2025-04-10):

Planul de masă nu urmează conturul plăcii (board outline)

LaviniaTudor003, 2025-04-10:
### **Descriere:**
Planul de masă nu este aliniat complet cu marginea plăcii, ceea ce poate cauza probleme de integritate electrică, scutare incompletă și chiar erori la fabricarea PCB-ului (ex. tăierea neuniformă a cuprului).

### **Imagine exemplu:**

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

### **Recomandare:**
Verifică dacă:

Conturul plăcii este corect detectat în layout (board outline setat corect)
Poligonul planului de masă este tras cu Pour Over All sau are restricții de clearance ajustate greșit
Polygonul a fost refăcut (Repour) după modificările la outline

mariad765, 2025-04-13:
Mulțumesc pentru sesizare!

Am verificat plane-ul de masă și confirm că:

-> Board outline-ul este setat corect și este detectat de tool.

-> Polygonul a fost inițial tras cu Pour Over All, însă e posibil să fi fost afectat de modificările ulterioare aduse conturului.

->Clearance-urile și restricțiile de la margine sunt în regulă, conform specificatiilor, insa este posibil ca acestea sa afecteze inca felul cum este pozitionat poligonul.

## 🔧 Mofificari:

Am folosit funcția **Ratsnest** pentru a actualiza și recalcula traseele și poligoanele de plan de masă după modificările recente din design. Această funcție face următoarele:

1. **Recalculează conexiunile**:
   - Actualizează traseele și conexiunile dintre pinii componentelor pe baza modificărilor făcute în layout (ex: trasarea de trasee noi, modificarea formei sau mărimii poligonului).

2. **Actualizează planul de masă (Ground Plane)**:
   - Refăcește poligonul planului de masă pentru a se asigura că toate golurile sunt umplute corect și că nu există zone neconectate după modificarea conturului plăcii.

3. **Arată conexiunile rămase**:
   - După utilizarea **Ratsnest**, se vizualizează o rețea de linii sau conexiuni virtuale care indică cum urmează să fie conectate componentele, oferind posibilitatea de a verifica dacă există trasee lipsă sau prea apropiate de marginea planului de masă.

În urma acestui proces, forma poligonului roșu este complet umplută și planul de masă urmează corect conturul plăcii.

Dacă mai sunt zone neacoperite, acestea sunt probabil cauzate de restricțiile de **clearance**, care sunt definite în fișierul **DRC** (Design Rule Check) primit, iar acest lucru nu ține de mine, ci de specificațiile primite.

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

Closed 2025-04-14.

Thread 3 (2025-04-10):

Structura repository-ului nu respectă cerințele proiectului

LaviniaTudor003, 2025-04-10:
### **Descriere:**
Conform cerințelor, directorul Manufacturing din repository trebuie să conțină toate fișierele necesare pentru fabricație, într-o structură clar definită.

### **Problemă:**

În structura actuală a repository-ului:

- Fișierul gerbers.zip lipsește complet
- Există subfolderele Bom și Cpl, dar nu este conform cerințelor – fișierele .bom și .cpl ar trebui să fie direct în Manufacturing, nu în subfoldere

### **Structură așteptată pentru Manufacturing:**

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

### **Captură Relevantă:**

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

### **Recomandare**
- Mută fișierele .bom și .cpl direct în folderul Manufacturing
- Adaugă fișierul gerbers.zip, care conține fișierele de fabricație generate

mariad765, 2025-04-13:
Mulțumesc pentru observații! Am identificat problema legată de structura directorului **Manufacturing**. Voi muta fișierele **.bom** și **.cpl** direct în folder și voi adăuga fișierul **gerbers.zip** conform cerințelor. Voi face modificările și le voi actualiza cât mai curând posibil.

Closed 2025-04-13.

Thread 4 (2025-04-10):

Eroare Copper Width

LaviniaTudor003, 2025-04-10:
### **Descriere:**
În layout-ul PCB curent, pad-urile componentei L1 (bobină) sunt prea mici, fapt care a generat o eroare de tip Copper Width la verificarea DRC.

### **Problemă:**
- Pad-urile SMD ale bobinei L1 nu respectă regula de lățime minimă a cuprului definită în DRC.
OBS: Acest lucru poate duce la probleme de fabricație sau slăbirea legăturii mecanice/electrice a bobinei pe placă.

### **Captură Relevantă:**

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

### **Recomandări:**
- Modifică footprint-ul bobinei L1 pentru a mări dimensiunea pad-urilor.
- Rulare completă a DRC după modificări pentru a confirma corectarea.

mariad765, 2025-04-13:
Am verificat eroarea semnalată legată de pad-urile componentei **L1 (bobină)** care nu respectă lățimea minimă de cupru definită în fișierul **DRC**.

### 🔍 **Observații**:
- Eroarea este de tip **Copper Width**, generată de faptul că dimensiunea pad-urilor SMD pentru L1 este prea mică.
- Această problemă provine din footprint-ul predefinit în **librăria furnizată în cadrul cerinței task-ului**.

### 📌 **Decizie**:
În urma discuției cu coordonatorul, s-a confirmat că această abatere este acceptabilă în contextul actual. Prin urmare, eroarea poate fi marcată ca _known and approved_ și nu necesită modificarea footprint-ului.

### ✅ **Status**:
Se poate da **approve** pentru această eroare, fără alte modificări.

### commit -

Closed 2025-04-14.

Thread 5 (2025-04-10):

Display-ul este mai mare decât carcasa în modelul 3D

LaviniaTudor003, 2025-04-10:
### **Descriere:**
În modelul 3D realizat în Fusion 360, display-ul integrat în dispozitiv depășește dimensiunile carcasei, ceea ce indică o eroare de aliniere sau de dimensionare între componente.

###  **Problemă:**
- Display-ul nu se încadrează complet în volumul carcasei.

### **Capturi Relevante:**

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

### **Recomandări:**
Asigură-te că:
- Display-ul este aliniat corect în ansamblu
- Dimensiunile carcasei sunt ajustate corespunzător sau că a fost selectat modelul corect al display-ului

mariad765, 2025-04-13:
Am analizat modelul 3D menționat în issue și, pe sistemul meu local, **display-ul este aliniat corect și nu depășește dimensiunile carcasei**.

## 🖥️ Este posibil ca diferența observată să fie cauzată de:
- Versiuni diferite de Fusion 360 sau setări locale de grafică/display;
- Neactualizarea completă a componentelor în ansamblu (_Update All_) la deschiderea modelului;
- Un model temporar incorect regenerat în workspace-ul altui utilizator.

## 📌 **Recomandare**:
Să fie verificat dacă toate componentele au fost actualizate local (click dreapta pe ansamblu > **Update**) și dacă modelul a fost sincronizat complet din cloud.

### În cazul în care problema persistă, foloseste ca referinta versiunea STEP sau STP pe care am exportat-o in directorul  Mechanical.

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

Closed 2025-04-13.

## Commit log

2025-03-27 schematic done
    [H1maria_v5.sch]
2025-04-06 added files and necesarry folders. readme incomplete yet
    [H1maria_placa v167.brd, H1maria_placa v167.csv, H1maria_v120_schematic.sch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]
2025-04-14 issue with id #2 solved. issue with id #4 solves (approved errors), issue with id #3 solved ( + added some more files to make sure everything is there )
    [H1maria_placa v167_BOM.csv, H1maria_placa_v168.brd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]

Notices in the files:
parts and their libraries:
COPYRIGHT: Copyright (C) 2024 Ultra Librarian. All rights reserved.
